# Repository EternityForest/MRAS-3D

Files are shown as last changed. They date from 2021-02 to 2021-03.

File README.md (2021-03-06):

# MRAS-3D

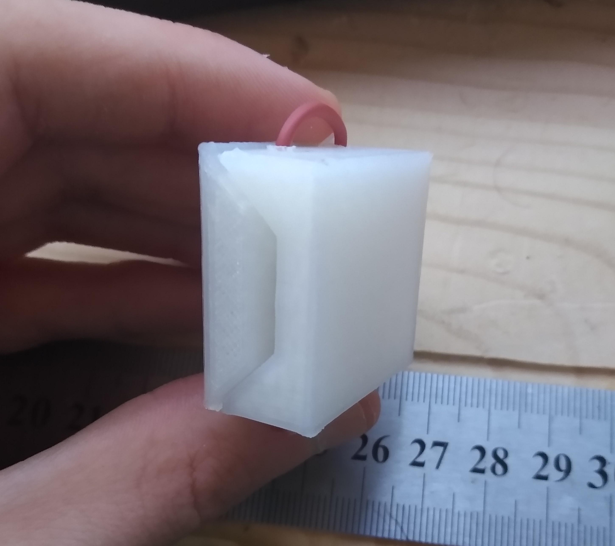
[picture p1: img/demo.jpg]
MRAS Rail


3D-Printed modular quick-release rail system

Designed to be printable in most orientations, without any special tuning.

It is meant for building modular storage and electronics, mounting devices to walls, and any other time where you'd like to use a DIN rail, but need something smaller for something non-critical.

A piece of filament bent into a U shape is used as a pin to connect the two pieces. Inserting the pin is rather easy, and once attached, they are nearly impossible to separate be any means besides pulling the pin.

Mechanical drawings are included, as is the full FreeCad Assembly3 document.

The system is based on 32mm tiles, with 2 pin holes 16mm apart. Tiles can be repeated to form a rail of any length. A 4.6mm hole in the middle of every male tile allows use as a wall mounted rail.

The gap between parts is meant to be covered by 1/4x1/8 foam tape, providing both extra pressure to hold the pin in place, and vibration isolation. It also keeps the flat area, which would need support to print upside-down, away from direct contact, as the burrs left by support interfere with fit unless you carefully sand.

The full finished products should normally be a multiple of 32, minus a gap on all sides for clearence. The peg holes should be 16mm from the ideal 32mm edge, not the real edge that allows for clearence.

It is also acceptable for the height of an item to be 16mm, with 48mm being a preferred dimension for shelves and storage.

For demo purposes, these blocks are exactly 32mm.

## Integrating into prints

Suggested rules for integrating rails into larger designs:

Male rails are probably more durable and have little to break, and almost nothing to catch on stuff. They should be used on walls, and the tops and fronts of things.

Female rails should be used on the backs and bottoms of things. This means bottoms will need to print with support.

I'm not sure what to do about left and right sides. I would think female on the left side(Looking at it's front) and male on the right seems reasonable, but there might also be cases where dual-male or dual-female is the best option.

## Compatibles:  

### 128mm rail
A wall mount rail wide enough for 4 32mm units.  Exported from the same file as the shelf.  Uses 16mm spaced
M4ish holes in the center of every 32mm unit, that have a chamver for most wood screws.

### 32mm Horizontal cable guide 
A cube-shaped hook, 32mm wide, to keep a cable going how you want it.

### 128mm decorative shelf
Has sun and moon designs on the sides.  Sticks forward a bit farther than you might like, 
as it was originally meant for a specific google alarm clock.   Has holes in the back for cables coming up from below.  

### Mini 32mm pencil cup
Holds a few pencils or similar items, maybe a whiteboard marker. Also has similas cable management in case you want to use it as a housing for a DIY LED light.

### 32mm Bending Jig with storage
Handy for if you want to use 14ga wire or something instead of filament.  
Keychain sized, and has storage for 2 extra clips, plus a pair of straightening guide holes.
Requires cleaning up the holes after printing.  
  
Absolutely not needed and primarily exists to waste 7 grams of filament at the end of a spool. 
However, the bits of filament are easy to lose and drop, so having a way to carry them may be a good thing.

### 64mm wide battery storage trays

AAA version stores 12x AAA plus two coin cells
18650 version stores 4x 18650 plus 2 AAs, one coin cell, and one AAA

WARNING: DO NOT USE THESE TO STORE COIN CELLS OR OTHER DANGEROUS BATTERIES WHERE KIDS CAN REACH

### 32MM Vertical Cable Guide

Tiny part with 2 side channels for cables.  To actually be able to hold the cables, use a 1/4 by 1/8 piece of single sided foam tape in the channels.  
  
### 32MM Adapter
Glue or screw this to anything to make it rail-mountable.  Has a centered cross of 3 M4 holes side to side at 10mm spacing. and 2 m3 holes 10mm above and below.  
  
This has special cutouts that let you use M4ish wood screws screwed in from the rail side without conflict.  
  
The M3(But not the M4) holes can also accept a nut threaded on from the rail side. But you should probably just  
use 3M VHB or something like that in most cases.  
  
### 64MM Cup  
  
48mm high by 64mm cup.  Contains one internal 32mm rail on the left side, for internally attaching other modules.

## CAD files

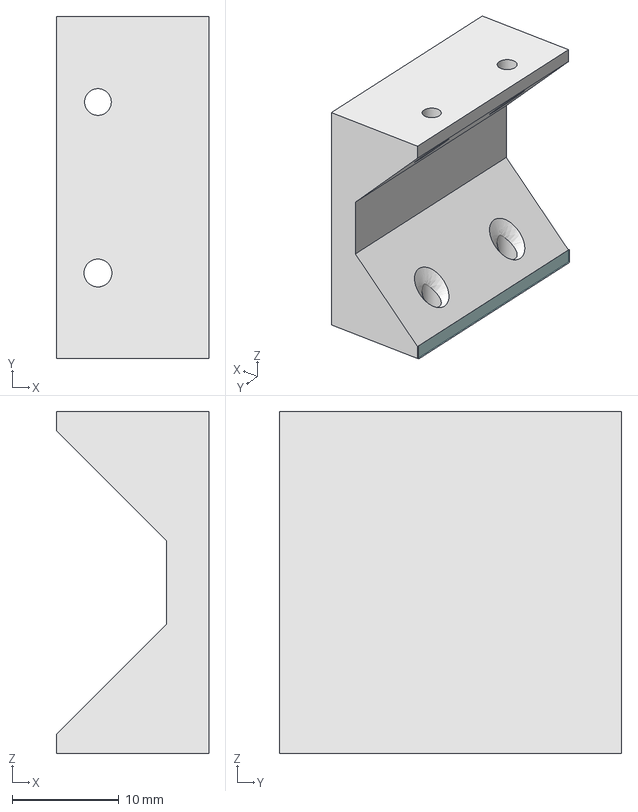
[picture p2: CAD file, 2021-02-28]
3DRail.FCStd
14.5 x 32.0 x 32.0 mm
_Element

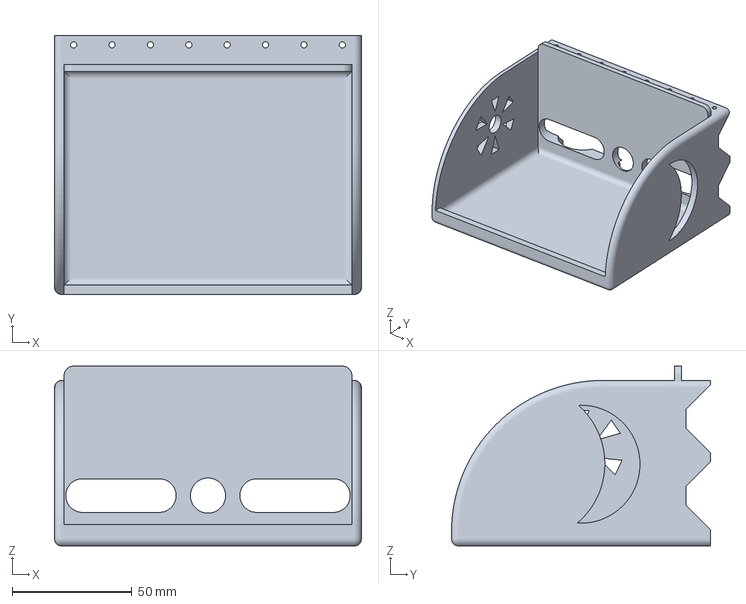
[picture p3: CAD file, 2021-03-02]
Compatibles/12CM Decorative Shelf/Shelf.amf
128.0 x 108.0 x 75.0 mm

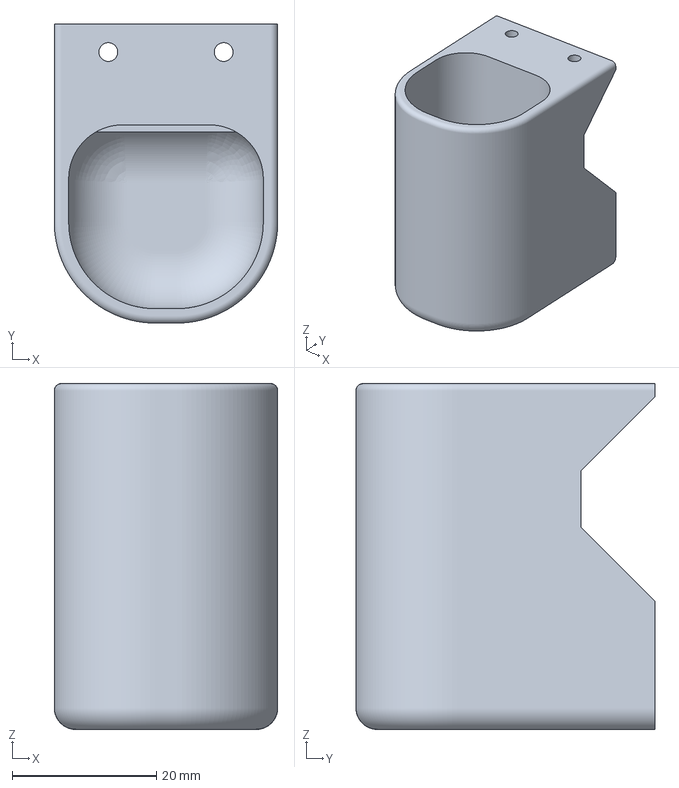
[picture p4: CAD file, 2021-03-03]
Compatibles/32MM pencil holder/PencilHolder.amf
31.0 x 41.5 x 48.0 mm

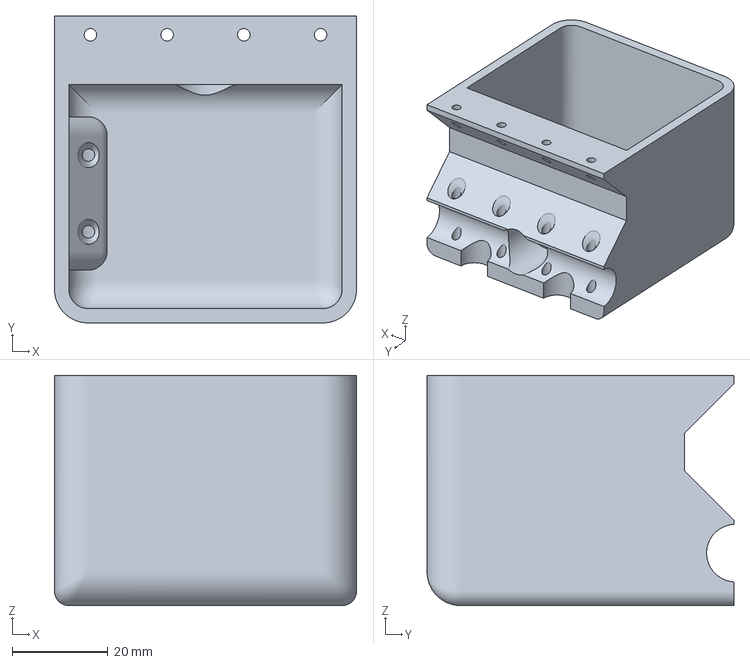
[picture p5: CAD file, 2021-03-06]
Compatibles/64mm cup/64mmcup.amf
63.0 x 64.0 x 48.0 mm

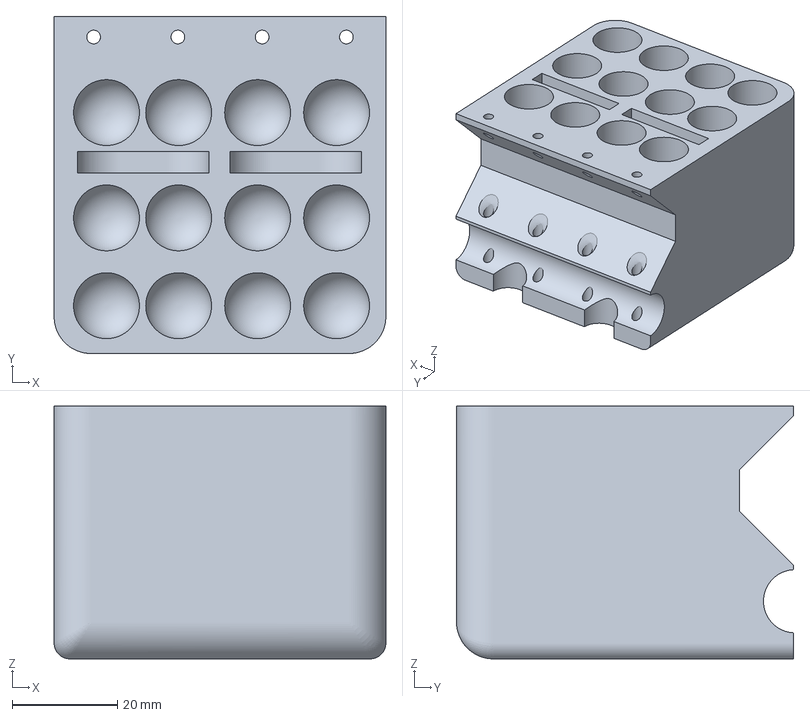
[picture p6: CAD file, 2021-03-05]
Compatibles/AAAHolder.amf
63.0 x 64.0 x 48.0 mm

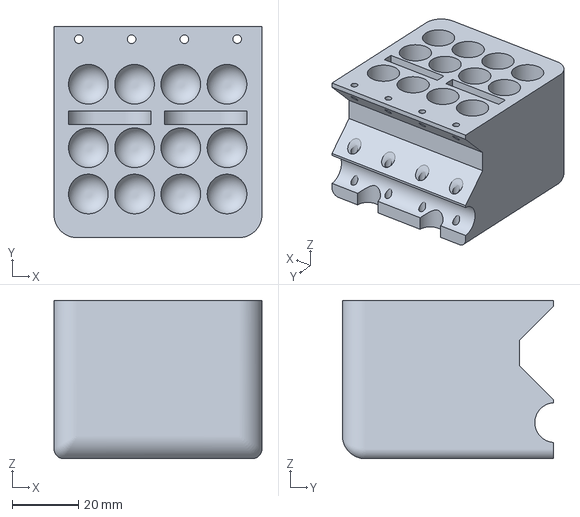
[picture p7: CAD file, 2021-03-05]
Compatibles/AAAHolder/AAAHolder.amf
63.0 x 64.0 x 48.0 mm

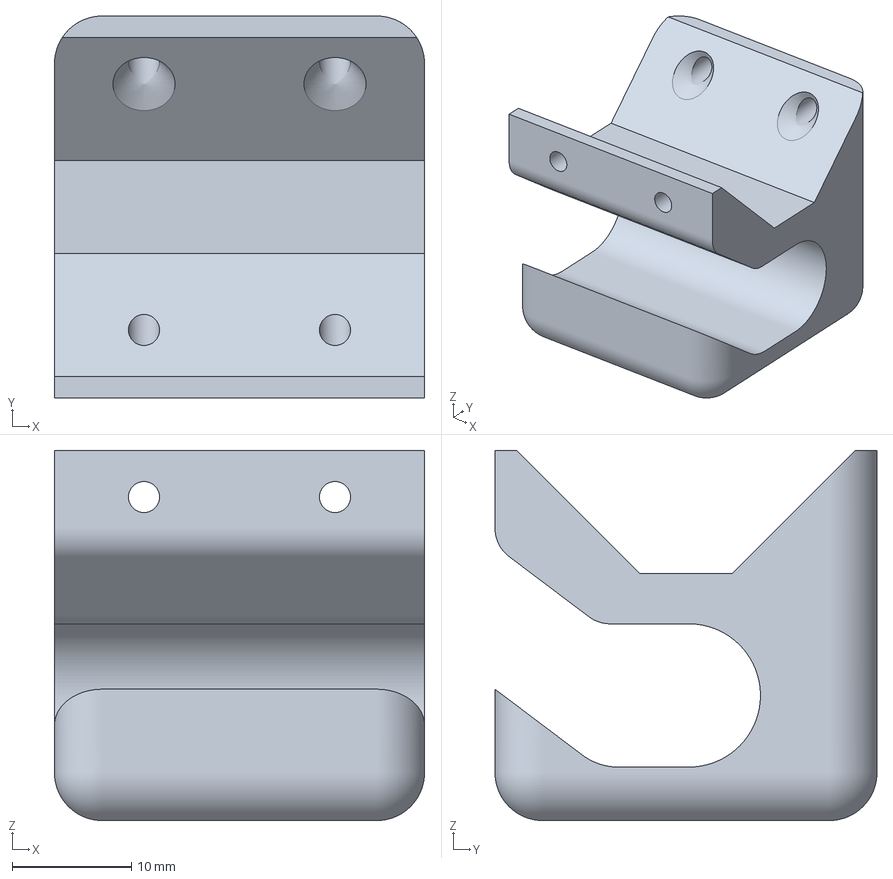
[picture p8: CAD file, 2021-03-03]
Compatibles/Cable Guide/CableGuide.amf
31.0 x 32.0 x 31.0 mm

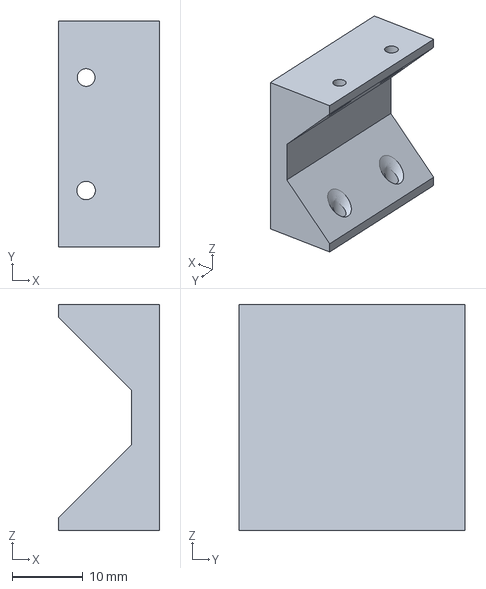
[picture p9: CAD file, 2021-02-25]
Printable Demo/Female32mmtile.amf
14.3 x 32.0 x 32.0 mm

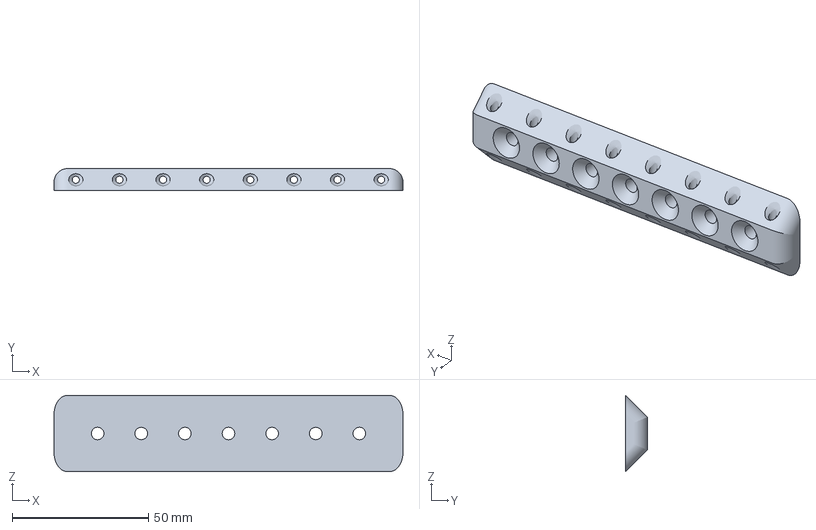
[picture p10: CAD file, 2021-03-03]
Rails/128mmFlushRail.amf
128.0 x 8.00 x 28.0 mm

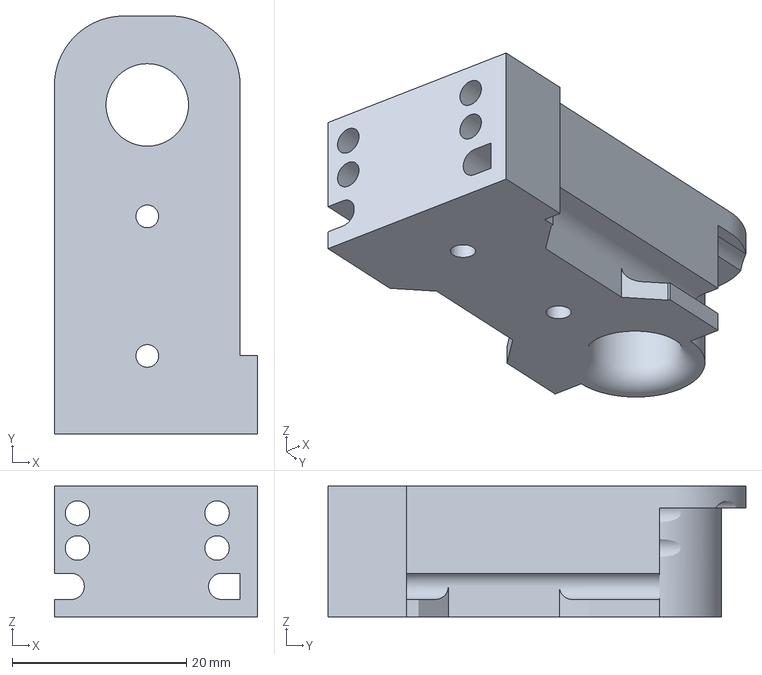
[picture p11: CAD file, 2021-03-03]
Tools/BendingJig/BendingJigWithStorage.amf
23.3 x 47.9 x 15.0 mm

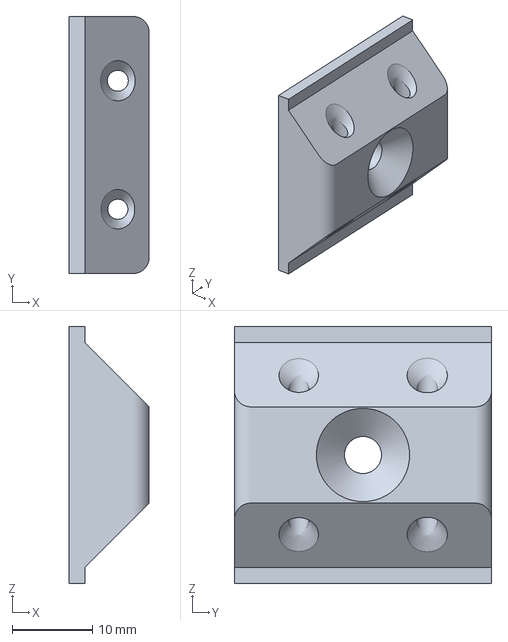
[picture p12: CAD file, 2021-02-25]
Printable Demo/Male32mmtile.amf
10.00 x 32.0 x 32.0 mm

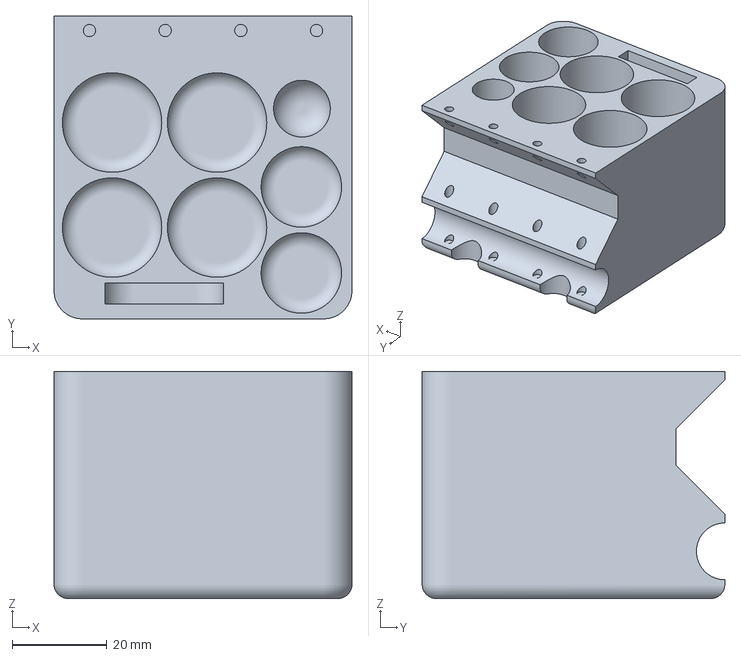
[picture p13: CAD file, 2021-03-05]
Compatibles/18650x4/18650x4.amf
63.0 x 64.0 x 48.0 mm

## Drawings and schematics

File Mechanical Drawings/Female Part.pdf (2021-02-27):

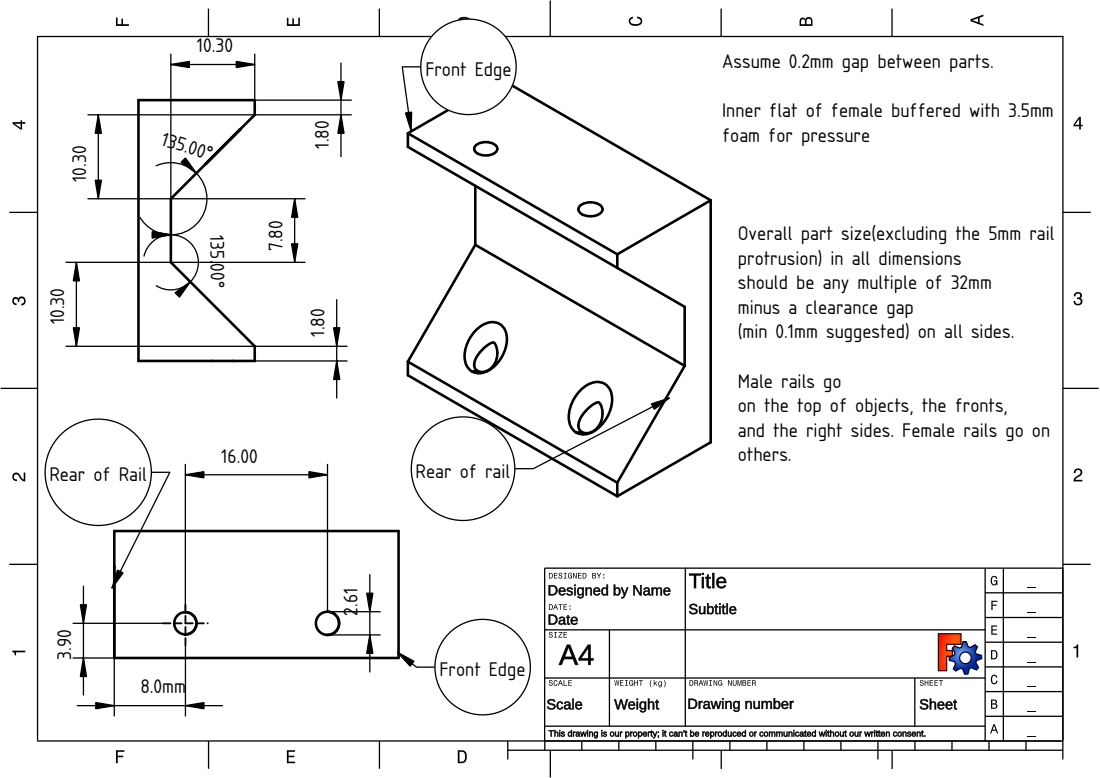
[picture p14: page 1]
Front Edge

Assume 0.2mm gap between parts.
Inner flat of female buffered with 3.5mm
foam for pressure

Overall part size(excluding the 5mm rail
protrusion) in all dimensions
should be any multiple of 32mm
minus a clearance gap
(min 0.1mm suggested) on all sides.
Male rails go
on the top of objects, the fronts,
and the right sides. Female rails go on
others.

Rear of rail

Rear of Rail

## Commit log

2021-02-27 Fix the drawings
    [3DRail.FCStd]
2021-02-28 Decorative shelf
    [128mmFlushRail.amf, 3DRail.FCStd, Shelf.amf]
2021-03-02 Add chamfer to 128mn shelf and rail
    [128mmFlushRail.amf, Shelf.amf]
2021-03-03 Flush rail file move
    [128mmFlushRail.amf]
2021-03-03 Add the pencil holder
    [PencilHolder.amf]
2021-03-03 Cable guide
    [CableGuide.amf]
2021-03-05 AAA and 18640 holders
    [18650x4.amf, AAAHolder.amf]
2021-03-06 64mm cup
    [64mmcup.amf]
